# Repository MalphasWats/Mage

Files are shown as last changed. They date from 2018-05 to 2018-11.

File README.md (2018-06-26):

# Mage

Mage is my handheld ATTiny85 gaming project.

I've had this project bouncing around in my head for probably about 3 years now. 
Initially, I wasn't sure I could get an ATTiny85 to drive an OLED, but then a little
while ago I worked out how I could use a set of 8x8 tiles and an index map to keep
the SRAM requirements down.

After some furious breadboarding I produced a simple prototype which I transferred to protoboard

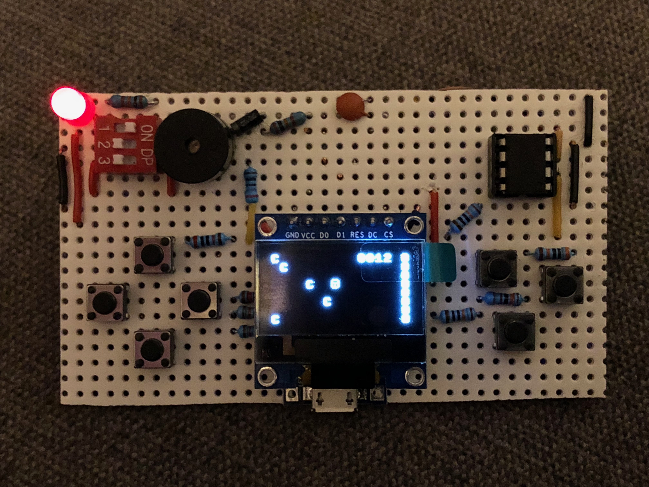
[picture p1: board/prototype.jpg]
Mage 0


This turned out to be an immensely frustrating exercise. I *thought* I would be happy with
a simple little protoboard device that I could make a little case for with acrylic or my 3D
printer. I was wrong - this thing only worked for about 30 seconds at a time before one
connection or other wobbled and broke. The screen was really flaky and I nearly got put off
entirely.

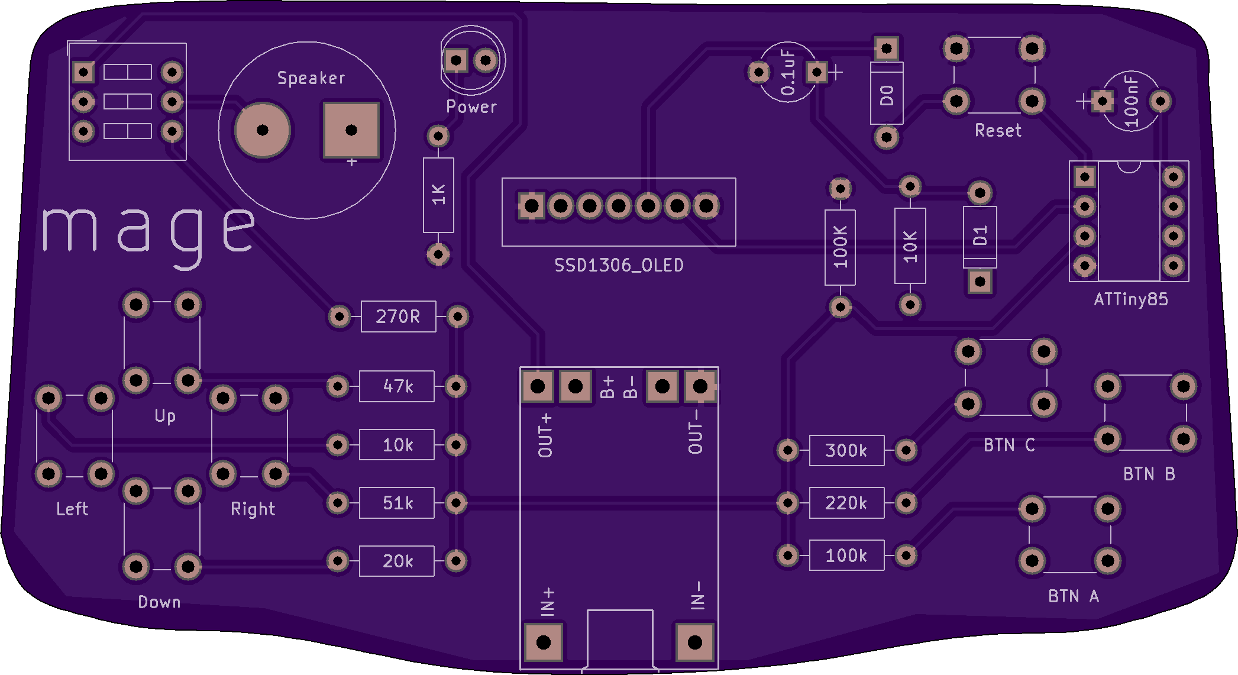
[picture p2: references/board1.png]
Mage 1


Enter KiCAD - I vaguely remembered a [Hackaday series on making a PCB in everything](https://hackaday.com/2016/11/17/creating-a-pcb-in-everything-kicad-part-1/).
I downloaded KiCAD and promptly wept for a few days. The learning curve on creating a PCB, not just from
scratch, but with absolutely no idea how to even use the software was **steep**. But after a few days, I
took another stab and came up with something not half bad. In the end, one of the hardest parts was getting
a board outline imported from a vector app - I used a photo of a GameBoy Advance and drew around it!

I sent the files off to OSH Park and waited. 

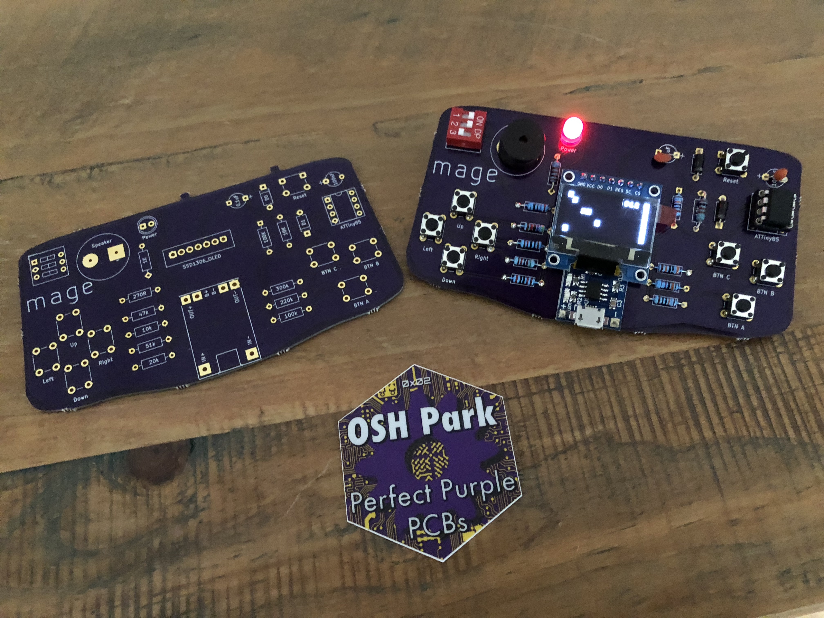
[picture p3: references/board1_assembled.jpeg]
Mage 1 Assembled


I was so very pleased with what I'd created, I immediately set off to create a demo game - that's the
game contained in this repository. My ambitions grew a little faster than my knowledge of C and I've
almost squeezed as much as possible out of the ATTiny85, which is quite satisfying.

The board itself wasn't quite what I had imagined way back when I first had the idea - I'd seen things like
the Gamebuino, which are really neat (and small). So I fired up KiCAD again and had another crack.

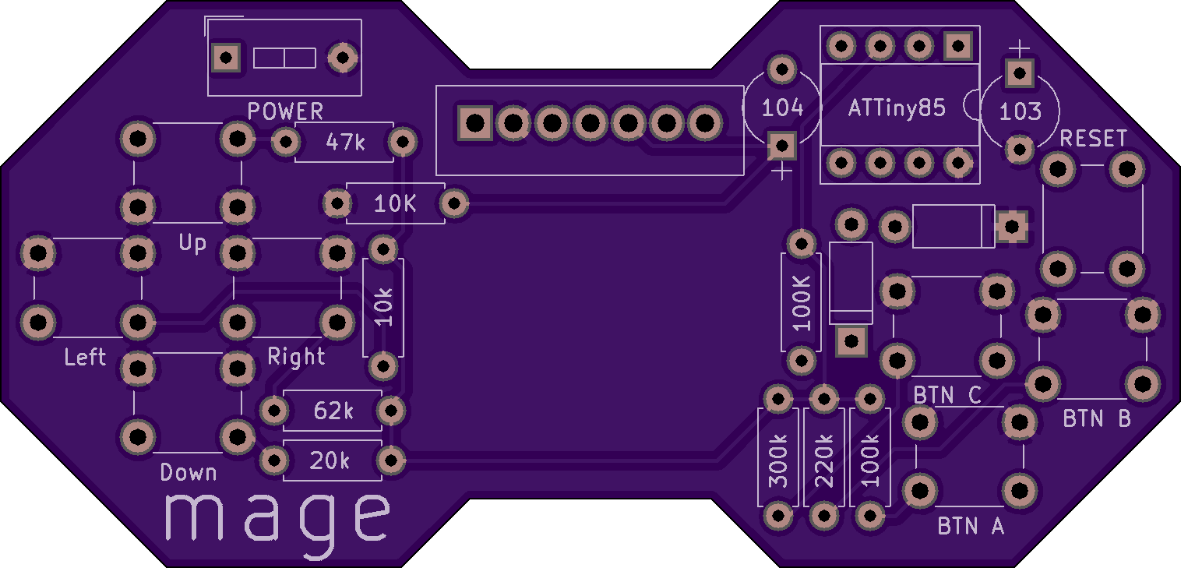
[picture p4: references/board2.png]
Mage 2


The second revision was much smaller - I used OpenSCAD to design the outline (3 octagons and a rectangle), 
which imported straight into KiCAD without any issue. The whole thing is smaller and I decided to use a
CR2032 cell to power it, instead of the 3.7v Lipo & charger that I originally put on the board.

Mage 2 Assembled

There were a few small issues, my first effort at soldering one nuked some of the traces and it took me a
while to realise what had caused the problems. I also discovered that the springiness of the battery clip
was too much for the small solder pads I'd defined and the battery clip pinged off taking the copper pad
with it!

I'm not entirely sure why it still works, but after a bit of hot glue action, the board was working again!
I wasn't happy with the layout - the screen overlapped awkwardly and the CR2023 was nice, but didn't actually
make it any thinner or smaller than a Lipo, so I returned to the drawing board and produced a *Final Version*
for which I am currently awaiting delivery.

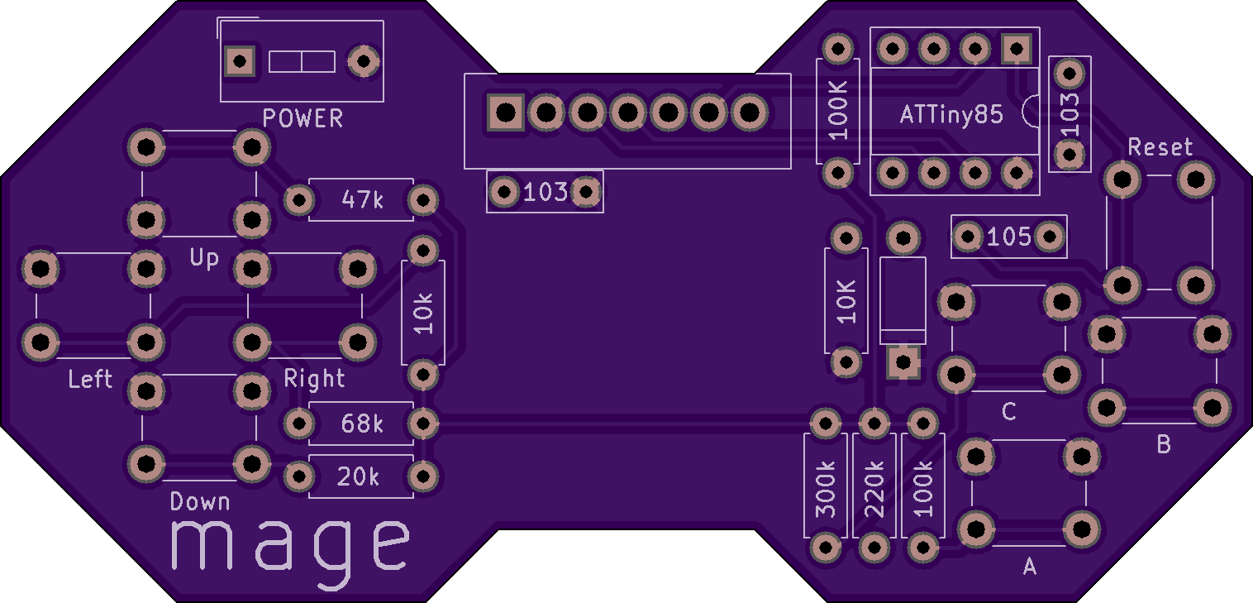
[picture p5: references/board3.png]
Mage 3


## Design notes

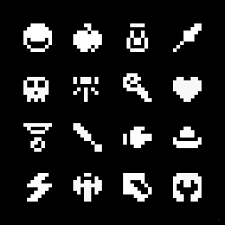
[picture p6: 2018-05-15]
references/items.png

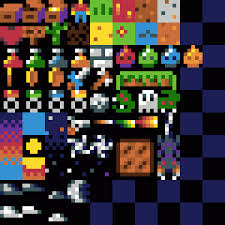
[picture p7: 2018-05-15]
references/colour tiles.jpg

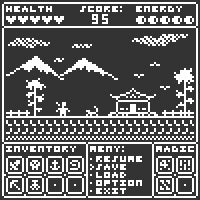
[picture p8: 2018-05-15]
references/ui.jpg

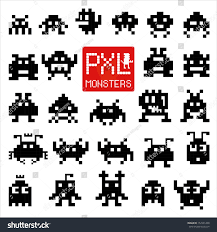
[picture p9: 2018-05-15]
references/monsters.png

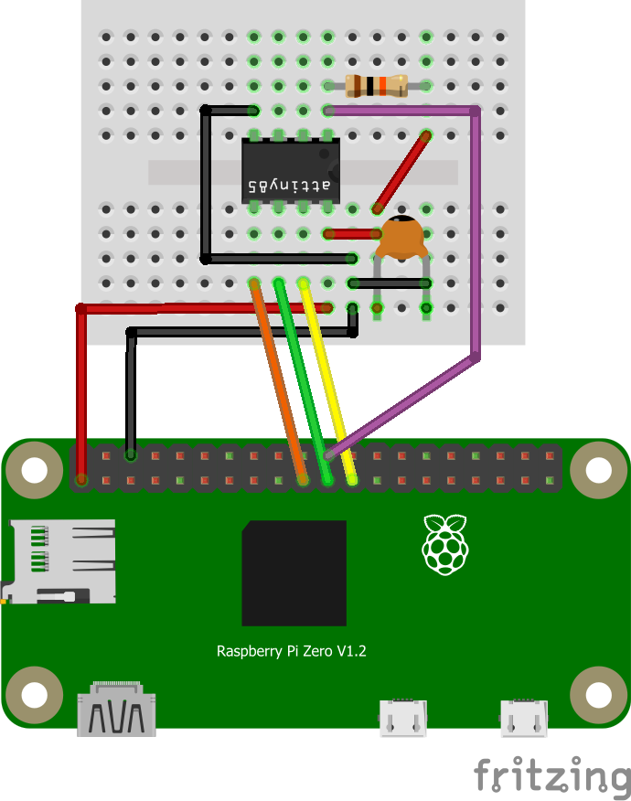
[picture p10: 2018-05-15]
programmer/RPiZero.png

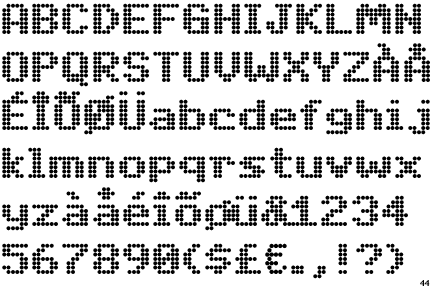
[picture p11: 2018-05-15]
references/DotMatrixSample.gif

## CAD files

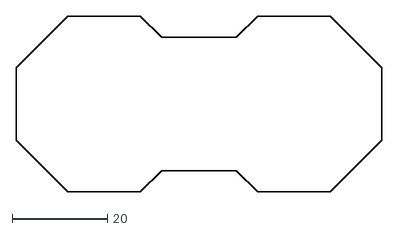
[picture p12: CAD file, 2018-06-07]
board/outline.dxf
77.0 x 37.0

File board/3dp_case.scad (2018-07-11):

s = 1.165; // 3mm wall thickness 1.165
b = 2.0;
d = 3+b;

module mage()
{
    translate([-20, 0, 0])
    {
    difference()
    {
        union()
        {
            difference()
            {
                rotate([0, 0, 360/16]) scale([s, s, 1])cylinder(r=20, h=d, $fn=8);
                translate([0, 0, b]) rotate([0, 0, 360/16]) cylinder(r=20, h=d, $fn=8);
            }

            difference()
            {
                translate([40, 0, 0]) rotate([0, 0, 360/16]) scale([s, s, 1]) cylinder(r=20, h=d, $fn=8);
                translate([0, 0, b]) translate([40, 0, 0]) rotate([0, 0, 360/16]) cylinder(r=20, h=d, $fn=8);
            }
        }

        translate([0, 0, b]) translate([20, 0, d/2]) cube([20, 28, d], center=true);
    }

    difference()
    {
        translate([20, 0, d/2]) scale([s, s, 1]) cube([12, 29, d], center=true);
        translate([0, 0, b]) translate([20, 0, d/2]) cube([16, 28, d], center=true);
    }
}
}

translate([20, 18.5, 0]) color("red") cube([2, 3, d+1]);
mage();

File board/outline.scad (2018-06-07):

rotate([0, 0, 360/16]) circle(r=20, $fn=8);

translate([40, 0, 0]) rotate([0, 0, 360/16]) circle(r=20, $fn=8);

translate([20, 0]) square([40, 28], center=true);

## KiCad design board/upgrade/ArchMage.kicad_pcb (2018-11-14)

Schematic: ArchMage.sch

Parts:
J1: ISP; Pin_Header_Straight_2x03_Pitch2.54mm
J2: DIP8; DIP-8_W7.62mm
U1: ATmega1284P-AU; TQFP-44_10x10mm_Pitch0.8mm

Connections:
AD2: J2.3, U1.35 (PA2)
GND: J1.6, J2.4, U1.6 (GND), U1.18 (GND), U1.28 (GND), U1.39 (GND)
MISO: J1.1, U1.2 (PB6)
MOSI: J1.4, U1.1 (PB5)
PB0: J2.5, U1.40 (PB0)
PB1: J2.6, U1.41 (PB1)
PB2: J2.7, U1.42 (PB2)
PB3: J2.2, U1.43 (PB3)
RESET: J1.5, J2.1, U1.4 (~RESET)
SCK: J1.3, U1.3 (PB7)
Vcc: J1.2, J2.8, U1.5 (VCC), U1.17 (VCC), U1.27 (AVCC), U1.38 (VCC)

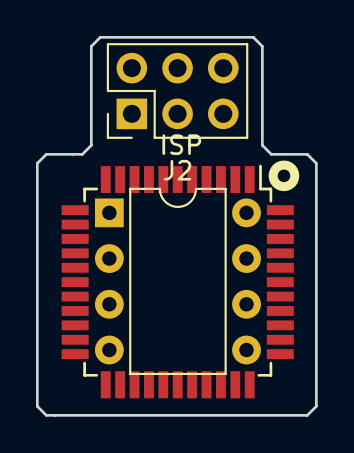
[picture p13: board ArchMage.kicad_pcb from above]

Board: 2 copper layers, 15.5 x 21.0 mm, 3 parts (0 on the bottom side), 11 nets, no tracks yet.

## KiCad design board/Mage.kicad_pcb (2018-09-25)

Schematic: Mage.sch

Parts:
BT1: 3.7v Lipo; LiPo_Pads
C0: 1.0uF; C_Rect_L7.0mm_W2.5mm_P5.00mm
C1, C2: 0.1uF; C_Rect_L7.0mm_W2.5mm_P5.00mm
D0: D_ALT; D_A-405_P7.62mm_Horizontal
LS1: Speaker; Generic_Speaker
R1: 47k; R_Axial_DIN0207_L6.3mm_D2.5mm_P7.62mm_Horizontal
R2: 20k; R_Axial_DIN0207_L6.3mm_D2.5mm_P7.62mm_Horizontal
R3: 10k; R_Axial_DIN0207_L6.3mm_D2.5mm_P7.62mm_Horizontal
R4: 68k; R_Axial_DIN0207_L6.3mm_D2.5mm_P7.62mm_Horizontal
R5: 100k; R_Axial_DIN0207_L6.3mm_D2.5mm_P7.62mm_Horizontal
R6: 220k; R_Axial_DIN0207_L6.3mm_D2.5mm_P7.62mm_Horizontal
R7: 300k; R_Axial_DIN0207_L6.3mm_D2.5mm_P7.62mm_Horizontal
R9: 100K; R_Axial_DIN0207_L6.3mm_D2.5mm_P7.62mm_Horizontal
R10: 10K; R_Axial_DIN0207_L6.3mm_D2.5mm_P7.62mm_Horizontal
SW0: Reset; SW_PUSH_6mm_h5mm
SW1: Up; SW_PUSH_6mm_h5mm
SW2: Down; SW_PUSH_6mm_h5mm
SW3: Left; SW_PUSH_6mm_h5mm
SW4: Right; SW_PUSH_6mm_h5mm
SW5: A; SW_PUSH_6mm_h5mm
SW6: B; SW_PUSH_6mm_h5mm
SW7: C; SW_PUSH_6mm_h5mm
SW8: POWER; SW_DIP_x1_W7.62mm_Slide
U1: ATTiny85; TQFP-44_10x10mm_Pitch0.8mm
U2: SSD1306_OLED; Wafer_Vertical20x5.8x7RM2.5-7

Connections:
+3V3: C1.2, C2.2, D0.1 (K), R10.1, SW1.1, SW2.1, SW3.1, SW4.1, SW5.1, SW6.1, SW7.1, SW8.2, U1.8 (Vcc), U2.2 (VCC)
GND: BT1.2, C0.2, C1.1, C2.1, LS1.2, R9.1, SW0.1, U1.4 (GND), U2.1 (GND), U2.7 (CS)
unnamed: BT1.1, SW8.1
unnamed: C0.1, D0.2 (A), R10.2, SW0.2, U1.1 (RST_ADC0), U2.5 (RESET)
unnamed: LS1.1, U1.5 (PB0)
unnamed: R1.1, R2.1, R3.1, R4.1, R5.1, R6.1, R7.1, R9.2, U1.3 (PB4_ADC2)
unnamed: R1.2, SW1.2
unnamed: R2.2, SW2.2
unnamed: R3.2, SW3.2
unnamed: R4.2, SW4.2
unnamed: R5.2, SW5.2
unnamed: R6.2, SW6.2
unnamed: R7.2, SW7.2
unnamed: U1.2 (PB3_ADC3), U2.6 (D/C)
unnamed: U1.6 (PB1), U2.3 (CLK)
unnamed: U1.7 (PB2_ADC1), U2.4 (MOSI)

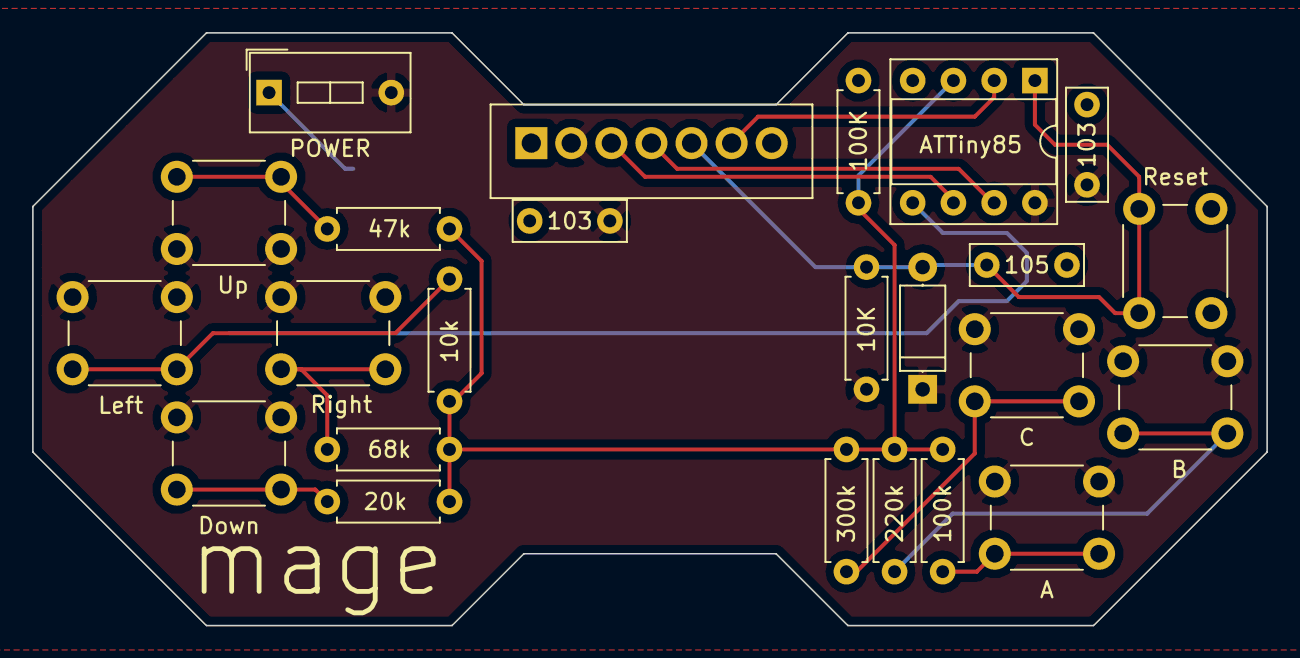
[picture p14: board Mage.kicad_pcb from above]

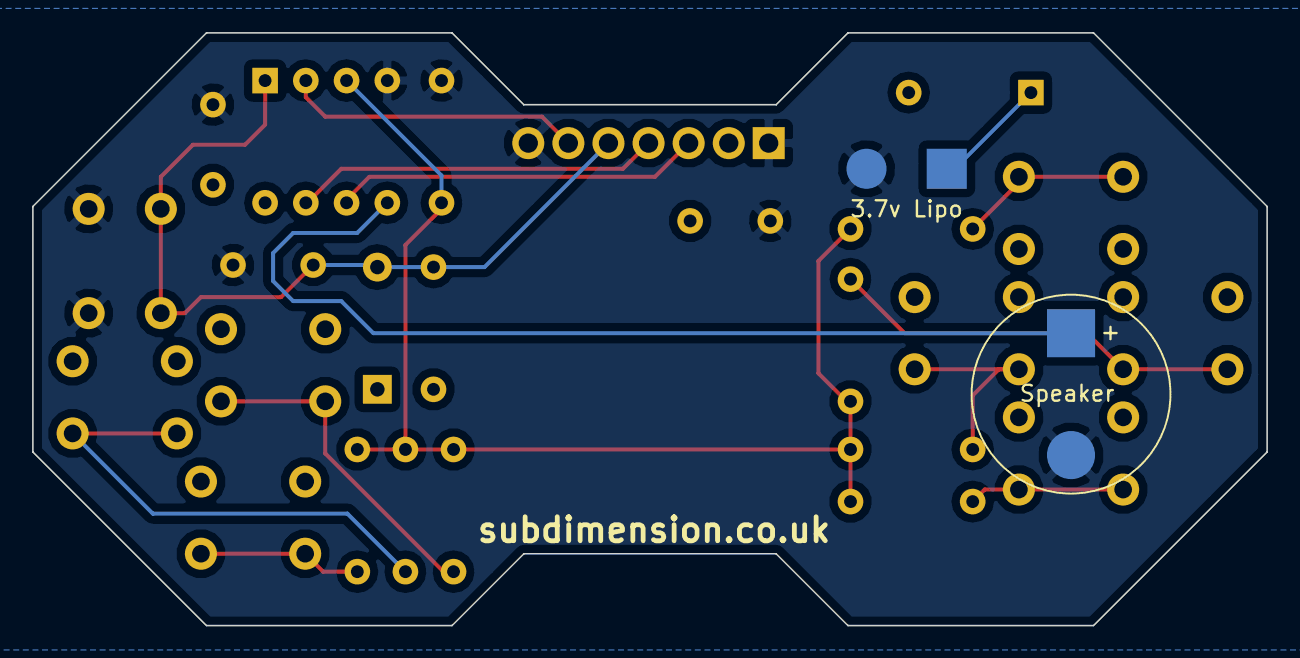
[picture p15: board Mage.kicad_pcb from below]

Board: 2 copper layers, 77.0 x 37.0 mm, 26 parts (2 on the bottom side), 16 nets.

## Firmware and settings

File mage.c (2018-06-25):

#include <avr/io.h>

#include "mage.h"
#include "oled.h"
#include "glyphs.h"
#include "beep.h"

unsigned int btn_timer = 0;
int btn_val = 0;

unsigned int t;
unsigned int spawn_timer;

int viewport_col = 0;
int viewport_row = 0;

byte cursor = 0;

item combat_actions[] = {
	(item){.glyph=98, .attributes=0},
	(item){.glyph=99, .attributes=0},
	(item){.glyph=100, .attributes=0},
};

item inventory[PLAYER_INVENTORY];

void display_map(location *loc)
{   
    int col, row, i;
    
    for (row=0 ; row<SCREEN_ROWS ; row++)
    {
        set_display_col_row(0, row);
        for (col=0 ; col<SCREEN_COLUMNS ; col++)
        {
            i = loc->width * (viewport_row+row) + (viewport_col+col);
            shift_out_block(&GLYPHS[pgm_read_byte(&loc->map[ i ])*8], FALSE);
        }
    }
}

/*void display_hud(unsigned int value)
{
    for (byte d=0 ; d<4 ; d++)    // Button Mapping
    {
        display_block( &GLYPHS[((value % 10)+DIGIT_OFFSET)*8], 4-d, 0);
        value = value / 10;
    }
    
    delay_ms(50);
}*/

/*void display_player(mob_type *player)
{
    display_block(&GLYPHS[player->glyph*8], player->position.x-viewport_col, (player->position.y-viewport_row));
}*/

/*mob_type *update_mobs(location *loc, mob_type *player)
{
    for(byte i=0 ; i<MAX_MOBS ; i++)
    {
        if (loc->mobs[i])
        {
            if (loc->mobs[i]->position.x == player->position.x && 
                loc->mobs[i]->position.y == player->position.y &&
                !loc->mobs[i]->dead)
            {
                return loc->mobs[i];
            }
            //TODO: update the mob
        }
    }
    return 0;
}*/

/*void display_mobs(location *loc)
{
    for(byte i=0 ; i<MAX_MOBS ; i++)
    {
        if (loc->mobs[i])
        {
            if (loc->mobs[i]->position.x >= viewport_col && loc->mobs[i]->position.x < viewport_col+SCREEN_COLUMNS && 
                loc->mobs[i]->position.y >= viewport_row && loc->mobs[i]->position.y < viewport_row+SCREEN_ROWS )
            {
                display_block(&GLYPHS[loc->mobs[i]->glyph*8], loc->mobs[i]->position.x-viewport_col, (loc->mobs[i]->position.y-viewport_row));
            }
        }
    }
}*/

void display_window(point top_left, byte width, byte height)
{
    byte b = 0;
    for(byte y=0 ; y<height ; y++)
    {
        for(byte x=0 ; x<width ; x++)
        {
            if(x==0 && y==0)
                b=106;
            else if(x==width-1 && y==0)
                b=107;
            else if(x==0 && y==height-1)
                b=108;
            else if(x==width-1 && y==height-1)
                b=109;
            else if(y==0 || y==height-1)
                b=110;
            else if(x==0 || x==width-1)
                b=111;
            else
                b=0; // space!
            
            display_block(&GLYPHS[b*8], x+top_left.x, y+top_left.y);
        }
    }
}

/*void display_string(const char *str, byte col, byte row)
{
    char buffer[16];
    strcpy_P(buffer, str);
    for(byte i=0 ; buffer[i] != '\0' ; i++)
    {
        display_block(&GLYPHS[(buffer[i]-32)*8], col+i, row);
    }
}*/

byte display_item_window(point top_left, item *items, byte num_items, byte width)
{
    byte height = num_items / width;
    if (num_items % width > 0)
        height += 1;
    
    //display_window((point){5, 4-h}, 6, h+2);
    byte col = 0;
    byte row = 0;
    
    //char cursor = 0;
    
    for(ever)
    {
        t = millis();
        btn_val = analog_read(ADC2);
        if (btn_timer == 0)
        {
            if (btn_val >= _LEFT-ADC_VAR && btn_val <= _LEFT+ADC_VAR)
            {
                cursor -= 1;
                click();
                btn_timer = t;
            }
            else if (btn_val >= _RIGHT-ADC_VAR && btn_val <= _RIGHT+ADC_VAR)
            {
                cursor += 1;
                click();
                btn_timer = t;
            }
            else if (btn_val >= _UP-ADC_VAR && btn_val <= _UP+ADC_VAR)
            {
                cursor -= 4;
                click();
                btn_timer = t;
            }
            else if (btn_val >= _DOWN-ADC_VAR && btn_val <= _DOWN+ADC_VAR)
            {
                cursor += 4;
                click();
                btn_timer = t;
            }
            else if (btn_val >= _A-ADC_VAR && btn_val <= _A+ADC_VAR)
            {
				click();
				btn_timer = t;
                return cursor;
            }
			else if (btn_val >= _B-ADC_VAR && btn_val <= _B+ADC_VAR)
            {
				cursor = 255;
				btn_timer = t;
				return cursor;
			}
        }
        
        if (t - btn_timer > BTN_DELAY)
            btn_timer = 0;
        
        if (cursor > 250)
            cursor = 0;
        else if (cursor >= num_items)
            cursor = num_items-1;
        
        for(byte i=0 ; i<height*4 ; i++)
        {
            col = i % 4;
            row = i / 4;
            if (i<num_items)
                display_block_(&GLYPHS[items[i].glyph*8], top_left.x+col, top_left.y+row, i == cursor);
            else
                display_block(&GLYPHS[0], top_left.x+col, top_left.x+row);
        }
        
    }
}

//http://tech-algorithm.com/articles/nearest-neighbor-image-scaling/
void display_block_embiggened(byte glyph, point top_left)
{
    byte block[8];
    word buffer[16] = {0}; // Initialise to zero
    
    for(byte i=0 ; i<8 ; i++)
        block[i] = pgm_read_byte(&GLYPHS[glyph*8]+i);
    
    //unsigned long x_ratio = 32769;//(unsigned long)((8<<16)/16) +1;
    //unsigned long y_ratio = 32769;//(unsigned long)((8<<16)/16) +1;
    
    byte x2;
    byte y2;
    for (byte i=0;i<16;i++) 
    {
        for (byte j=0;j<16;j++) 
        {
            x2 = (byte)((j*32769)>>16) ;
            y2 = (byte)((i*32769)>>16) ;
            if (block[y2] & (1 << x2))
                buffer[i] |= 1 << j;
        }
    }
    
    set_display_col_row(top_left.x, top_left.y);
    for (byte i=0 ; i<16 ; i++)
    {
        shift_out((buffer[i] >> 8), LSBFIRST);
    }
    
    set_display_col_row(top_left.x, top_left.y+1);
    for (byte i=0 ; i<16 ; i++)
    {
        shift_out((buffer[i] & 0xff), LSBFIRST);
    }
}

void battle_mode(mob_type *player, mob_type *opponent)
{
    btn_timer = 0;
    
    //clear screen
    clear_display();
    
    crap_beep(_A4, 20);
    delay_ms(10);
    crap_beep(_A5, 35);
    delay_ms(30);
    crap_beep(_B5, 20);
    delay_ms(10);
    crap_beep(_C5, 35);
    
    
    //draw ui
    //display_block(&GLYPHS[32*8], 1, 1);
    //display_block(&GLYPHS[DIGIT_OFFSET*8], 2, 1);
    //display_block(&GLYPHS[DIGIT_OFFSET*8], 3, 1);
    
    display_block(&GLYPHS[102*8], 5, 4);
    display_block(&GLYPHS[103*8], 5+player->num_actions+1, 4);
    
    //TODO: Need to be cleverer about lining these up
    display_block(&GLYPHS[102*8], 5, 2);
    display_block(&GLYPHS[103*8], 5+opponent->num_actions+1, 2);
    
    //draw player TODO: scale x2
    display_block_embiggened(player->glyph, (point){.x=1, .y=6});
    
    //draw opponent TODO: scale x2
    display_block_embiggened(opponent->glyph, (point){.x=13, .y=2});

    byte turn=0;
	byte p_action=0;
    
    for(ever)
    {
        //update countdown
        
        /* Display player health */
        for(byte i=0 ; i<((player->hitpoints & 0xf0) >> 4) ; i++)
        {
            if( i >= (player->hitpoints & 0x0f) )
                display_block(&GLYPHS[104*8], 0+i, 5);
            else
                display_block(&GLYPHS[105*8], 0+i, 5);
        }
        
        /* Display opponent health */
        for(byte i=0 ; i<((opponent->hitpoints & 0xf0) >> 4) ; i++)
        {
            if( i >= (opponent->hitpoints & 0x0f) )
                display_block(&GLYPHS[104*8], 15-i, 1);
            else
                display_block(&GLYPHS[105*8], 15-i, 1);
        }
        
        if(opponent->dead || player->dead)
        {
            delay_ms(1000);
            break;
        }
        
        //choose opponent action(s)
        for(byte i=0 ; i<opponent->num_actions ; i++)
        {
            display_block(&GLYPHS[97*8], 6+i, 2);
        }
        
        // Clear player actions
        for(byte i=0 ; i<player->num_actions ; i++)
            display_block(&GLYPHS[0], 6+i, 4);
        
        byte player_turn = TRUE;
        player->actions = 0;
        //await player actions
        while(player_turn)
        {
            //byte a = display_item_window((point){.x=6, .y=6}, (byte[3]){239, 240, 241}, 3, 3, FALSE);
            byte a = 255;
            while(a == 255)
                a = display_item_window((point){.x=6, .y=6}, &combat_actions[0], 3, 3);
            display_block(&GLYPHS[(98+a)*8], p_action+6, 4);
            player->actions |= (a+1) << (p_action*3);
            p_action += 1;
            
            if (p_action == player->num_actions)
                player_turn = FALSE;
            else
                display_block(&GLYPHS[96*8], 6+p_action, 4);
        }
        
        //resolve combat
        crap_beep(_A4, 20);
        delay_ms(10);
        crap_beep(_A5, 35);
        delay_ms(30);
        crap_beep(_B5, 20);
        delay_ms(10);
        crap_beep(_C5, 35);
             
        byte p_attack_mod = 0;
        byte p_defence_mod = 0;
        byte o_attack_mod = 0;
        byte o_defence_mod = 0;
        
        for(byte i=0 ; i<5 ; i++)
        {
            byte pa = (player->actions >> (i*3)) & 0x0007;
            if (pa == 2)
                p_defence_mod += 3;
            else if (pa == 3)
                p_attack_mod += 3;
            else if (pa == 1)
            {
                if ( (rng() % 20) + player->attack + p_attack_mod > opponent->defence + o_defence_mod)
                {
                    if (player->damage >= (opponent->hitpoints & 0x0f))
                    {
                        opponent->hitpoints = opponent->hitpoints & 0xf0;
                        opponent->dead = TRUE;
                        //opponent->glyph = 20;
                        display_block_embiggened(20, (point){.x=13, .y=2});
                        spawn_timer = t;
                    }
                    else
                        opponent->hitpoints -= player->damage;
                }
            }
            
            
            byte oa = (opponent->actions >> (i*3)) & 0x0007;
            if (oa == 2)
            {
                o_defence_mod += 3;
                display_block(&GLYPHS[99*8], 6+i, 2);
            }
            else if (oa == 3)
            {
                o_attack_mod += 3;
                display_block(&GLYPHS[100*8], 6+i, 2);
            }
            
            if (oa == 1)
            {
                display_block(&GLYPHS[98*8], 6+i, 2);
                if ( (rng() % 20) + opponent->attack + o_attack_mod > player->defence + p_defence_mod)
                {
                    if (opponent->damage >= (player->hitpoints & 0x0f))
                    {
                        player->hitpoints = player->hitpoints & 0xf0;
                        player->dead = TRUE;
                        //player->glyph = 20;
                        display_block_embiggened(player->glyph, (point){.x=1, .y=6});
                    }
                    else
                        player->hitpoints -= opponent->damage;
                    
                }
            }
        }
            
        //show result
        delay_ms(200);
        
        turn += 1;
        p_action = 0;
        //opponent_actions = 0;
    }
}

byte collide_at(location *loc, byte col, byte row)
{
    // odd collide, even passable, TODO: above 128
    return pgm_read_byte(&loc->map[ loc->width * row + col ]) % 2;
}

int main (void) 
{
    // Setup
    //DDRB = (1<<SDA) | (1<<DC) | (1<<SCL) | (1<<SND); // Configure Outputs
    
    init_timer();
    initialise_oled();
    clear_display();
    
    PORTB |= 1 << DC;           // HIGH
    
    display_image(&LOGO[0], 3, 3, 10, 2);
    crap_beep(_A5, 140);
    delay_ms(5);
    crap_beep(_A8, 60);
    
    delay_ms(SPLASH_DELAY);
    
    PORTB &= ~(1 << DC);        // LOW
    send_command(0xA7);        // INVERTEDDISPLAY
    PORTB |= 1 << DC;           // HIGH
    
    //unsigned int delta = 0;
    
    byte map_dirty = TRUE;
    
    build_location_portals();
    location *current_location = &village;
    
    /*current_location->mobs[0] = &(mob_type){
        .glyph = (PLAYER_OFFSET+7),   // Blob
        .position = {.x=10, .y=8},
    
        .hitpoints = (4<<4) | 4,
        .damage = 1,
        .attack = 0,
        .defence = 5,
        .num_actions = 1,
        
        .actions = 0b01010101, // blobs just attack
    
        .dead = FALSE,
    };*/
        
    //mob_type mob1 = MOBS[BLOB];
    current_location->mobs[0] = &BLOB; //&mob1; //MOBS[BLOB];
    current_location->mobs[0]->position.x = 10;
    current_location->mobs[0]->position.y = 8;
    
    //mob_type mob2 = MOBS[BLOB];
    current_location->mobs[1] = &BLOB; //&mob2; //MOBS[BLOB];
    current_location->mobs[1]->position.x = 11;
    current_location->mobs[1]->position.y = 5;

    //mob_type mob3 = MOBS[GNOME];
    current_location->mobs[2] = &GNOME;
    current_location->mobs[2]->position.x = 15;
    current_location->mobs[2]->position.y = 1;
        
    current_location->containers[0] = &(container){
        .glyph=54,
        .position={.x=18, .y=6},
        .items={CHICKEN_LEG},
    };
    
    //for(byte i=1 ; i<MAX_CONTAINERS ; i++)
    //{
    //    current_location->containers[i] = NULL_CONTAINER;
   // }

    
    mob_type player = {
        .glyph = PLAYER_OFFSET,
        .position = current_location->portal_in,
    
        .attack = 1,
        .defence = 6,
        .hitpoints = (3<<4) | 3,
        .damage = 2,
        .num_actions = 2,
        
        .actions = 0, // Not applicable to player
    
        .dead = FALSE,
    };
	
	//item inventory[12];
	inventory[0] = APPLE;
	/*inventory[1] = NULL_ITEM;
	inventory[2] = NULL_ITEM;
	inventory[3] = NULL_ITEM;
	inventory[4] = NULL_ITEM;
	inventory[5] = NULL_ITEM;
	inventory[6] = NULL_ITEM;
	inventory[7] = NULL_ITEM;
	inventory[8] = NULL_ITEM;
	inventory[9] = NULL_ITEM;
	inventory[10] = NULL_ITEM;
	inventory[11] = NULL_ITEM;*/
        
    //container loot;
    
    for(ever)
    {
        t = millis();
        
        btn_val = analog_read(ADC2);
        
        //display_hud(btn_val); // Debug buttons
        if (btn_timer == 0)
        {
            rng(); // cycle the rng to try to get different values
            if (btn_val >= _LEFT-ADC_VAR && btn_val <= _LEFT+ADC_VAR)
            {
                if (!collide_at(current_location, player.position.x-1, player.position.y))
                {
                    player.position.x -= 1;
                    map_dirty = TRUE;
                    click();
                }
                
                btn_timer = t;
            }
            else if (btn_val >= _RIGHT-ADC_VAR && btn_val <= _RIGHT+ADC_VAR)
            {
                if (!collide_at(current_location, player.position.x+1, player.position.y))
                {
                    player.position.x += 1;
                    map_dirty = TRUE;
                    click();
                }
                btn_timer = t;
            }
            else if (btn_val >= _UP-ADC_VAR && btn_val <= _UP+ADC_VAR)
            {
                if (!collide_at(current_location, player.position.x, player.position.y-1))
                {
                    player.position.y -= 1;
                    map_dirty = TRUE;
                    click();
                }
                
                btn_timer = t;
            }
            else if (btn_val >= _DOWN-ADC_VAR && btn_val <= _DOWN+ADC_VAR)
            {
                if (!collide_at(current_location, player.position.x, player.position.y+1))
                {
                    player.position.y += 1;
                    map_dirty = TRUE;
                    click();
                }
                
                btn_timer = t;
            }
            else if (btn_val >= _A-ADC_VAR && btn_val <= _A+ADC_VAR)
            {
                btn_timer = t;
                if (player.position.x == current_location->portal_out.x && 
                    player.position.y == current_location->portal_out.y &&
                    current_location->return_to != 0)
                {
                    player.position = current_location->portal_in;
                    current_location = current_location->return_to;
                    map_dirty = TRUE;
                    click();
                }
                else 
                {
                    for (byte i=0 ; i<MAX_PORTALS ; i++)
                    {
                        if (player.position.x == current_location->portals[i]->portal_in.x && 
                            player.position.y == current_location->portals[i]->portal_in.y)
                        {
                            current_location = current_location->portals[i];
                            player.position.x = current_location->portal_out.x;
                            player.position.y = current_location->portal_out.y;
                            
                            map_dirty = TRUE;
                            click();
                            
                            break;
                        }
                    }
                    
                    for (byte i=0 ; i<MAX_CONTAINERS ; i++)
                    {
                        if (player.position.x == current_location->containers[i]->position.x && 
                            player.position.y == current_location->containers[i]->position.y)
                        {
                            // Display contents
                            crap_beep(_A4, 150);
                            delay_ms(50);
                            crap_beep(_A5, 100);
                            display_window((point){5, 2}, 6, 4);
                            byte selected = display_item_window(
                                            (point){.x=6, .y=3},
                                            &current_location->containers[i]->items[0], 
                                            CONTAINER_SIZE,
                                            4
                                           );
                            
							if (selected < 255)
							{
								for(byte slot=0 ; slot<PLAYER_INVENTORY ; slot++)
								{
									if (inventory[slot].glyph == 0 && current_location->containers[i]->items[selected].glyph != 0)
									{
										inventory[slot] = current_location->containers[i]->items[selected];
										current_location->containers[i]->items[selected] = NULL_ITEM;
									}
								}
							}
                            
                            map_dirty = TRUE;
                            
                            break;
                        }
                    }
                }
            }
            else if (btn_val >= _B-ADC_VAR && btn_val <= _B+ADC_VAR)
            {
                map_dirty = TRUE;
                
                click();
                
                btn_timer = t;
            }
            else if (btn_val >= _C-ADC_VAR && btn_val <= _C+ADC_VAR)
            {
                map_dirty = TRUE;
                    
                click();
                
                display_window((point){5, 1}, 6, 5);
                byte selected = 0;
                cursor = 0;
                while (selected < 255)
                {
                    for(byte i=0 ; i<((player.hitpoints & 0xf0) >> 4) ; i++)
                    {
                        if( i >= (player.hitpoints & 0x0f) )
                            display_block(&GLYPHS[104*8], 5+i, 0);
                        else
                            display_block(&GLYPHS[105*8], 5+i, 0);
                    }
                    
                    selected = display_item_window((point){.x=6, .y=2}, &inventory[0], PLAYER_INVENTORY, 4);
                    if (selected < 255)
                    {   
                        if (inventory[selected].attributes & CONSUMABLE)
                        {
                            //TODO: if I ever implement mana, need to check here
                            if ((player.hitpoints & 0x0f) + (inventory[selected].attributes & HP) > player.hitpoints >> 4)
                                player.hitpoints = (player.hitpoints & 0xf0) | (player.hitpoints >> 4);
                            else
                                player.hitpoints += (inventory[selected].attributes & HP);
                            
                            inventory[selected] = NULL_ITEM;
                        }
                        click();
                    }
                }
                
                btn_timer = t;
            }
            /*else if (btn_val >= _D)
            {
                map_dirty = TRUE;
                    
                click();
                
                display_window((point){0, 0}, 16, 8);
                display_string(PSTR("PAUSED"), 5, 0);
                
                //TODO: Display pause screen
                //Player Health / Mana
                //Player Level / XP (when implemented)
                //Player kills? maybe
                
                while(analog_read(ADC2) > 50){}
                //btn_timer = t;
            }*/
        }
        
        if (t - btn_timer >= BTN_DELAY)
            btn_timer = 0;
        if (t - spawn_timer >= SPAWN_DELAY)
            spawn_timer = 0;
        
        if (player.position.x == 255)
            player.position.x = 0;
        if (player.position.x > current_location->width-1)
            player.position.x = current_location->width-1;
        
        if (player.position.y == 255)
            player.position.y = 0;
        if (player.position.y > current_location->height-1)
            player.position.y = current_location->height-1;
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

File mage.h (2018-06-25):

#ifndef MAGE_H
# define MAGE_H

#define F_CPU 8000000

#include <avr/pgmspace.h>

#include "utils.h"
#include "maps.h"
#include "mobs.h"

#define SPLASH_DELAY    1500
#define BTN_DELAY       180
#define SPAWN_DELAY     45000

/* Button ADC Values */
#define _UP     695
#define _DOWN   852
#define _LEFT   930
#define _RIGHT  608
#define _A      512
#define _B      320
#define _C      252
#define _AC     584

#define ADC_VAR 2

#define PLAYER_INVENTORY 12

        
/*  0000  0      1000  8
    0001  1      1001  9
    0010  2      1010  A
    0011  3      1011  B
    0100  4      1100  C
    0101  5      1101  D
    0110  6      1110  E
    0111  7      1111  F */
        
static const byte LOGO[] PROGMEM = {
    
    0x00, 0x00, 0x04, 0x08, 0x18, 0x37, 0x3F, 0x0F,     0x03, 0x00, 0x00, 0x00, 0x00, 0x00, 0x00, 0x00,     // HAT (Top) 
    0x00, 0x00, 0x3F, 0x7E, 0x10, 0x38, 0x1C, 0x0E,     0x04, 0x02, 0x0E, 0x1C, 0x38, 0x10, 0x3F, 0x7E,     // M (Top)
    0x00, 0x00, 0x3F, 0x7E, 0x81, 0xC1, 0xC1, 0xC1,     0xC0, 0xC1, 0xC1, 0xC1, 0xC1, 0xC0, 0xBF, 0x7E,     // A
    0x00, 0x00, 0x3F, 0x7E, 0x80, 0xC0, 0xC0, 0xC0,     0xC0, 0xC1, 0xC1, 0xC1, 0xC1, 0xC0, 0x80, 0x00,     // G
    0x00, 0x00, 0x3F, 0x7E, 0x81, 0xC1, 0xC1, 0xC1,     0xC0, 0xC0, 0xC0, 0xC0, 0xC0, 0xC0, 0x80, 0x00,     // E    
        
    0x00, 0x38, 0x5C, 0x2C, 0xEC, 0xEC, 0xEC, 0xEC,     0xEC, 0xEC, 0x2C, 0x5C, 0x3C, 0x38, 0x00, 0x00,     // HAT (Bottom)  
    0x00, 0x00, 0x7C, 0xFE, 0x00, 0x00, 0x00, 0x00,     0x00, 0x00, 0x00, 0x00, 0x00, 0x00, 0x7E, 0xFC,     // M
    0x00, 0x00, 0x7C, 0xFE, 0x80, 0x80, 0x80, 0x80,     0x80, 0x00, 0x80, 0x80, 0x80, 0x80, 0x7E, 0xFC,     // A
    0x00, 0x00, 0x7C, 0xFE, 0x01, 0x03, 0x03, 0x03,     0x03, 0x03, 0x83, 0x83, 0x83, 0x81, 0x7E, 0xFC,     // G
    0x00, 0x00, 0x7C, 0xFE, 0x01, 0x83, 0x83, 0x83,     0x83, 0x03, 0x03, 0x03, 0x03, 0x02, 0x00, 0x00,     // E
};

void display_map(location *loc);
//void display_hud(unsigned int value);
//void display_player(mob_type *player);
//mob_type *update_mobs(location *loc, mob_type *player);
//void display_mobs(location *loc);
void display_window(point top_left, byte width, byte height);
//void display_string(const char *str, byte col, byte row);
byte display_item_window(point top_left, item *items, byte num_items, byte width);
void display_block_embiggened(byte glyph, point top_left);
void battle_mode(mob_type *player, mob_type *opponent);
byte collide_at(location *loc, byte row, byte col);

#endif

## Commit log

2018-05-15 PCB Files
    [Pixel.kicad_pcb, Pixel.sch, outline.dxf]
2018-05-17 rotated reset diode
    [Pixel.kicad_pcb, Pixel.sch]
2018-05-17 fixed connections
    [Pixel.kicad_pcb]
2018-05-19 tweak device for avrdude
2018-05-20 millis() only returns an int
2018-05-20 rework OLED driver to support SH1106 controller.
    [mage.c, mage.h, oled.c]
2018-05-20 return to correct position when changing location
    [mage.c]
2018-05-21 battle screen framework functionality
2018-05-21 attack bracket misaligned
2018-05-21 nearest neighbour rescale (still not working)
    [mage.c]
2018-05-27 tweaked button values
2018-06-01 added container functionality
    Containers can now be created & filled and things taken from them (but
    there is currently no player inventory!)
2018-06-07 New, smaller PCB
    [Mage.kicad_pcb, Mage.sch, Pixel.kicad_pcb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]
2018-06-14 deprecate D button
2018-06-15 missing button timer caused single press to register as multiple
    [mage.c]
2018-06-17 loot from mobs, reworked glyphs to make space
    [mage.c]
2018-06-22 new prototype uses SSD1306
2018-06-22 respawn after death, mobs respawn, fix bug with combat
    [mage.c, mage.h]
2018-06-25 reworked board to make it neater
    Added decoupling capacitor for OLED
    Removed CR2032, replaced with Lipo
    Tweaked layout
    [Mage.kicad_pcb, Mage.sch]
2018-07-11 initial thoughts
    [3dp_case.scad]
2018-09-25 updated board to KiCAD 5.0
    [Mage-2018-09-25-12-19-57.sch, Mage.kicad_pcb, Mage.sch]
2018-10-09 ArchMage initial prototype
    [ArchMage-B.Cu.gbr, ArchMage-B.Mask.gbr, ArchMage-B.Paste.gbr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]
2018-10-11 Scroll added
    Scroll adds an ISP header as a plug-in extension for the ATtiny85 because I get fed up with plugging and un-plugging (and de-bending the pins) when I'm developing
    [_saved_scroll.sch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]
2018-10-11 schematic annotations
    [_saved_scroll.sch, scroll.kicad_pcb, scroll.sch]
2018-11-14 changes that I've forgotten now
    [ArchMage.kicad_pcb, ArchMage.sch]
